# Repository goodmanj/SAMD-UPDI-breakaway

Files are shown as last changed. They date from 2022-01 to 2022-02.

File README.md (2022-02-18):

# SAMD-UPDI-breakaway
 A USB-to-UART-to-UPDI circuit board designed in KiCAD, based on Quentin Bolsee's [SAMD11C14 UART/UPDI programmer](https://fabacademy.org/2020/labs/ulb/students/quentin-bolsee/projects/samd11c_uart-updi/).  This version is designed so you can snap it in half to create a USB-to-UART adapter, and a UART-to-UPDI adapter, that can be used separately or joined together.  If you don't plan to use the "breakaway" feature, you don't need to solder in the 6-pin headers, and you might want to delete the internal slot to make it stronger.

* [Detailed assembly instructions](https://docs.google.com/document/d/1IBKZu-5q0hexmYGWNFWA64giY4mmglZQRK6Q2b19Nos/)
* [Quentin Bolsee's "SAMD11C_Serial" Arduino sketch](https://github.com/qbolsee/SAMD11C_serial): firmware for this board
* [Fab SAM Core for Arduino](https://github.com/qbolsee/ArduinoCore-fab-sam): Arduino core needed for Quentin's sketch

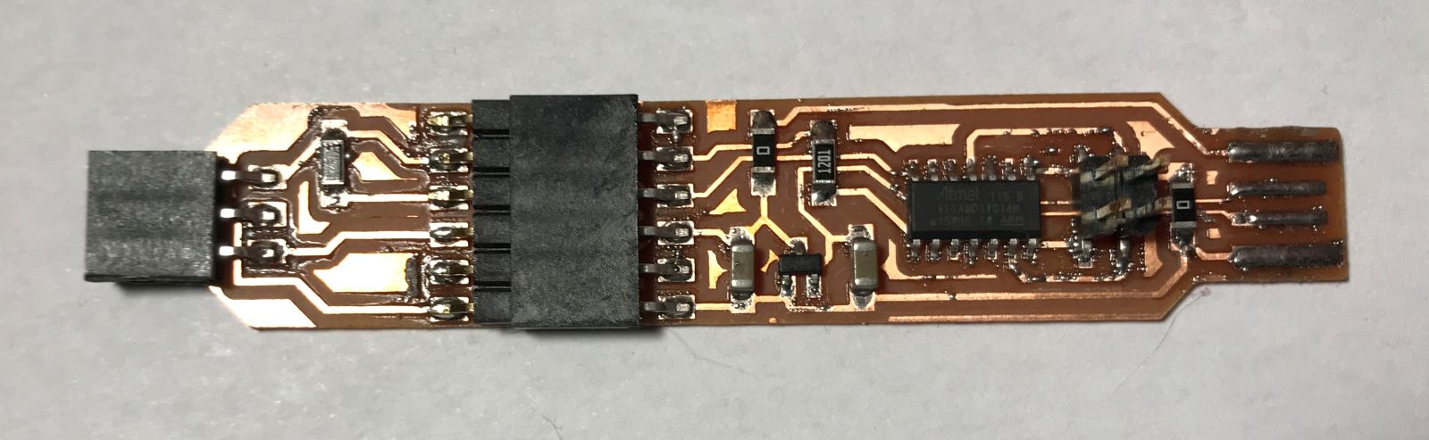
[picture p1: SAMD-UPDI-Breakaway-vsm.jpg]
Hero shot of board

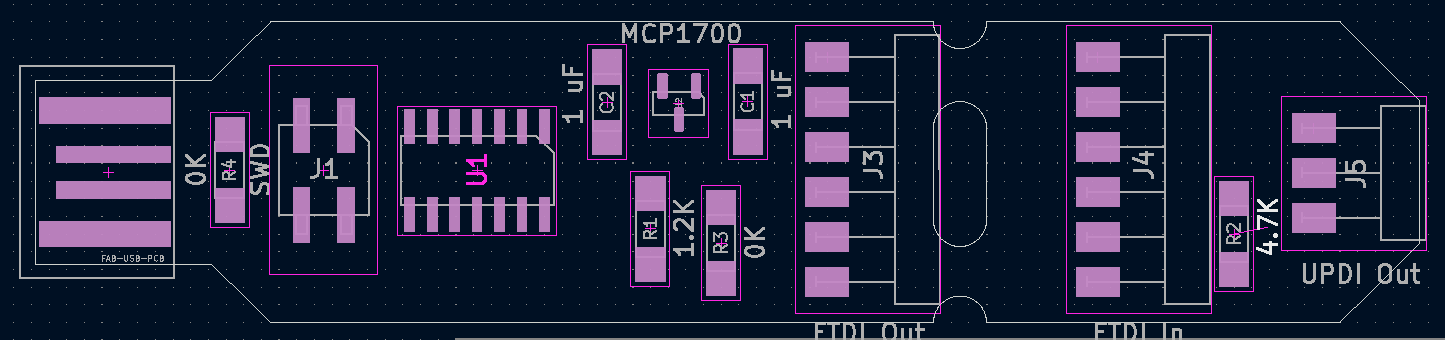
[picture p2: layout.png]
Component layout


## USB Port Backplate
You may find that the USB port is a little too skinny to fit nicely into some USB ports.  You can 3-d print a [Back Plate](BackPlate.stl) and glue or double-sided-tape it to the board to make it fit better.

 # Parts List
* [MCP1700T-3302E/TT LDO Voltage Regulator 5v->3.3v](https://www.mouser.com/ProductDetail/579-MCP1700T3302E-TT)
* [ATSAMD11C14A-SSNT SAMD microcontroller](https://www.mouser.com/ProductDetail/556-ATSAMD11C14ASSNT)
* [M20-8750242 2.54mm 2+2 DIL SMT header](https://www.mouser.com/ProductDetail/855-M20-8750242)
* [M20-8890645 2.54mm 6 way horzontal male SMT header](https://www.mouser.com/ProductDetail/855-M20-8890645)
* [M20-7910642R 2.54mm 6 way horzontal female SMT header](https://www.mouser.com/ProductDetail/855-M20-7910642R)  Qty: 2
* [1206 SMD resistor 4.7k](https://www.mouser.com/ProductDetail/652-CR1206-JW-472ELF)
* [1206 SMD resistor 1.2k](https://www.mouser.com/ProductDetail/652-CR1206FX-1201ELF)
* [1206 SMD zero-ohm SMD jumper](https://www.mouser.com/ProductDetail/652-CR1206-J-000ELF)
* [1206 SMD 1uF ceramic capacitors](https://www.mouser.com/ProductDetail/187-CL31B105KAHNFNE) Qty: 2

# Blinky Version
There is also a [version of this board with LED lights](Blinky-version/) to indicate serial data activity.  You will need two additional 1206 1.2k resistors, and two 1206 1.2k LEDs.

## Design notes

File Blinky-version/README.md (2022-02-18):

# Blinky Version
This version of the USB-to-UART-to-UPDI board includes LEDs to indicate serial port activity.  The red LED will turn on when this board has power: it will flicker *off* when data is being sent.  The green LED will turn on when the board you're talking to has power; it will flicker *off* when data is received.

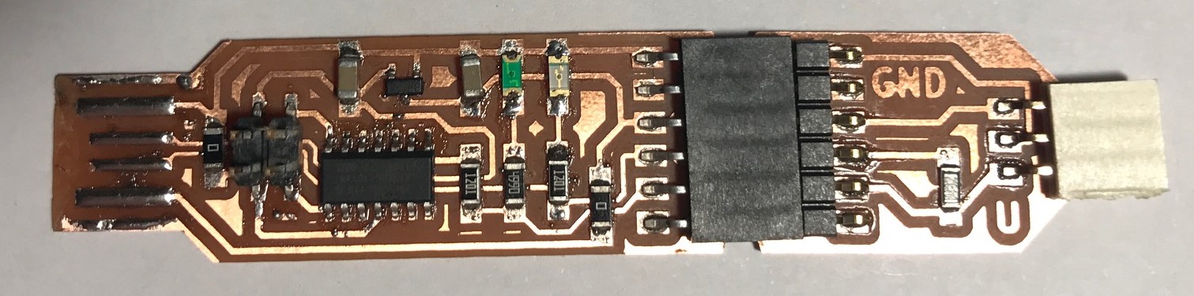
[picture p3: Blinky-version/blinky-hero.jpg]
Hero shot of board
 
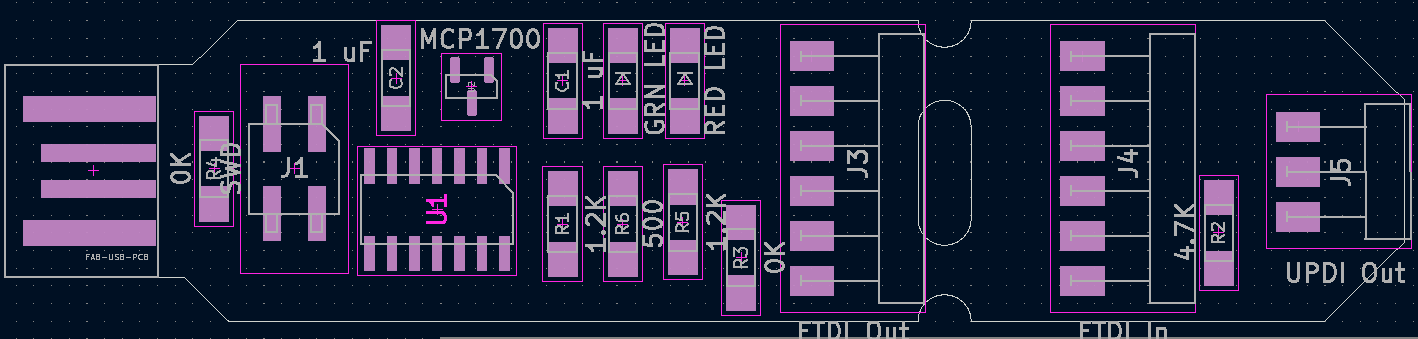
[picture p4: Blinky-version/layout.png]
Board Components
 
 # Parts List
* [MCP1700T-3302E/TT LDO Voltage Regulator 5v->3.3v](https://www.mouser.com/ProductDetail/579-MCP1700T3302E-TT)
* [ATSAMD11C14A-SSNT SAMD microcontroller](https://www.mouser.com/ProductDetail/556-ATSAMD11C14ASSNT)
* [M20-8750242 2.54mm 2+2 DIL SMT header](https://www.mouser.com/ProductDetail/855-M20-8750242)
* [M20-8890645 2.54mm 6 way horzontal male SMT header](https://www.mouser.com/ProductDetail/855-M20-8890645)
* [M20-7910642R 2.54mm 6 way horzontal female SMT header](https://www.mouser.com/ProductDetail/855-M20-7910642R)  Qty: 2
* [1206 SMD resistor 4.7k](https://www.mouser.com/ProductDetail/652-CR1206-JW-472ELF)
* [1206 SMD resistor 1.2k](https://www.mouser.com/ProductDetail/652-CR1206FX-1201ELF) Qty: 2
* [1206 SMD resistor 500](https://www.digikey.com/en/products/detail/yageo/RC1206FR-07499RL/728944) Qty: 1
* [1206 SMD zero-ohm SMD jumper](https://www.mouser.com/ProductDetail/652-CR1206-J-000ELF) Qty: 2
* [1206 SMD 1uF ceramic capacitors](https://www.mouser.com/ProductDetail/187-CL31B105KAHNFNE) Qty: 2
* [1206 SMD Red Clear LED](https://www.digikey.com/en/products/detail/liteon/LTST-C150CKT/269214)
* [1206 SMD Green Clear LED](https://www.digikey.com/en/products/detail/liteon/LTST-C150GKT/269216)

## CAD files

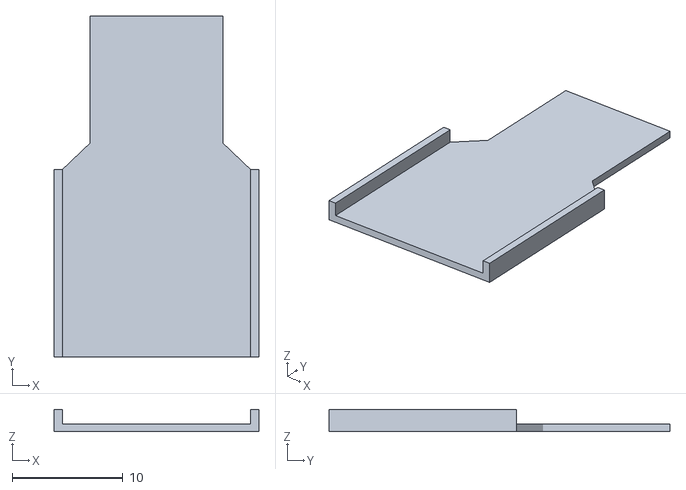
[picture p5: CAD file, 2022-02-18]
BackPlate.stl
18.5 x 30.8 x 2.00

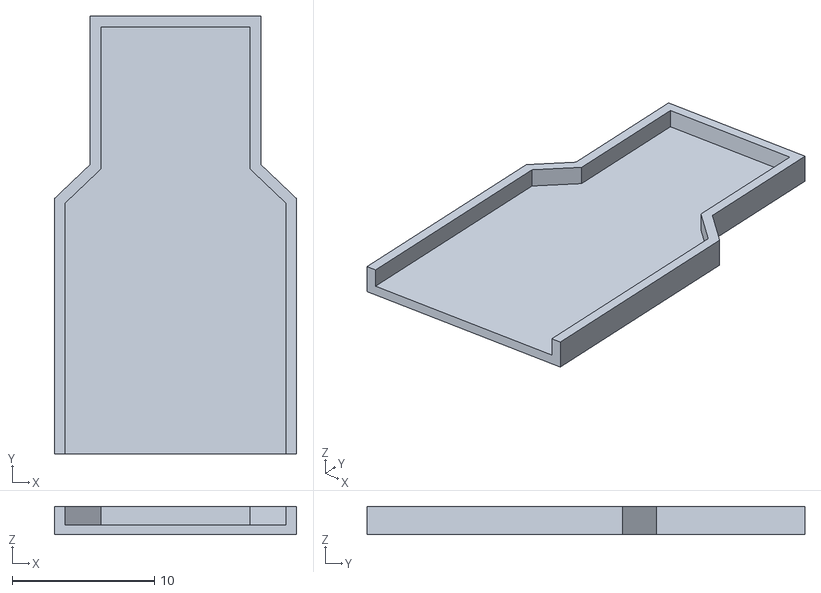
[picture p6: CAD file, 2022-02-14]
BackPlate-small.stl
17.0 x 30.8 x 2.00

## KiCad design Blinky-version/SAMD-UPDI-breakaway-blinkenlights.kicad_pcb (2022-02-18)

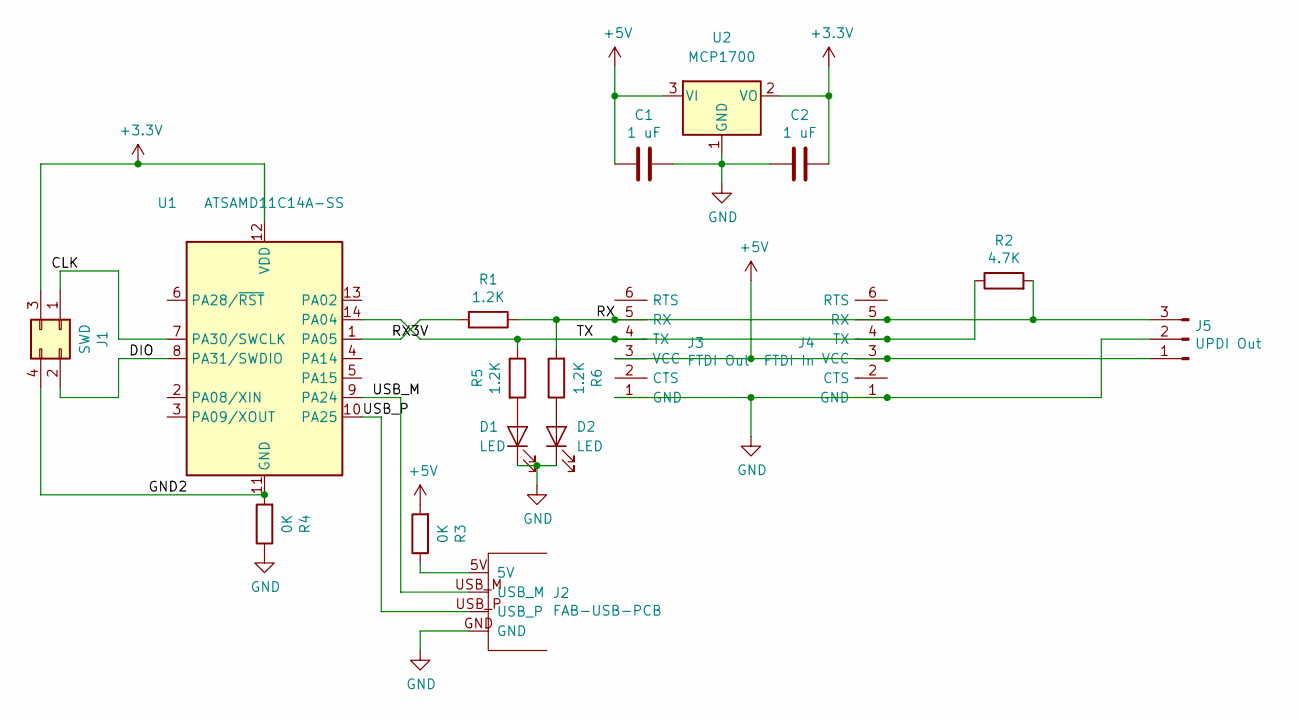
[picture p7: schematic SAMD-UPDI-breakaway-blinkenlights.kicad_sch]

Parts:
C1, C2: 1 uF; C_1206
D1, D2: LED; LED_1206
J1: SWD; PinHeader_2x02_P2.54mm_Vertical_SMD
J2: FAB-USB-PCB; FAB_USB-A-PCB
J3: FTDI Out; PinHeader_FTDI_01x06_P2.54mm_Horizontal_SMD
J4: FTDI In; PinHeader_FTDI_01x06_P2.54mm_Horizontal_SMD
J5: UPDI Out; PinHeader_1x03_P2.54mm_Horizontal_SMD
R1, R5, R6: 1.2K; R_1206
R2: 4.7K; R_1206
R3, R4: 0K; R_1206
U1: ATSAMD11C14A-SS; SOIC-14_3.9x8.7mm_P1.27mm
U2: MCP1700; SOT-23

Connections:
+3V3: C2.1, J1.3, U1.12 (VDD), U2.2 (VO)
+5V: C1.2, J3.3 (VCC), J4.3 (VCC), J5.1, R3.2, U2.3 (VI)
/DIO: J1.2, U1.8 (PA31/SWDIO)
/GND2: J1.4, R4.2, U1.11 (GND)
/RX: J3.5 (RX), J4.5 (RX), J5.3, R1.1, R2.2, R6.2
/RX3V: R1.2, U1.1 (PA05)
/TX: J3.4 (TX), J4.4 (TX), R2.1, R5.1, U1.14 (PA04)
/USB_M: J2.USB_M, U1.9 (PA24)
/USB_P: J2.USB_P, U1.10 (PA25)
GND: C1.1, C2.2, D1.1 (K), D2.1 (K), J2.GND, J3.1 (GND), J4.1 (GND), J5.2, R4.1, U2.1 (GND)
unnamed: D1.2 (A), R5.2
unnamed: D2.2 (A), R6.1
unnamed: J1.1, U1.7 (PA30/SWCLK)
unnamed: J2.5V, R3.1

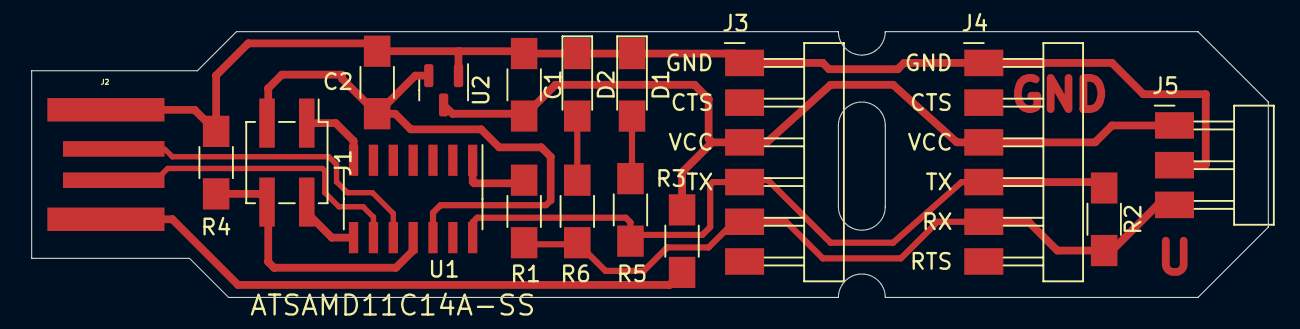
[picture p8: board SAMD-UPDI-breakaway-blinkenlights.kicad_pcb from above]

Board: 2 copper layers, 79.1 x 17.0 mm, 17 parts (0 on the bottom side), 14 nets.

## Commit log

2022-01-20 First draft, repo creation.
    Board hasn't been programmed or tested yet!
    [SAMD-UPDI-breakaway.kicad_pcb, SAMD-UPDI-breakaway.kicad_sch, SAMD-UPDI-breakaway.sch]
2022-02-14 Outline and Trace files added
    [SAMD-UPDI-breakaway.kicad_sch]
2022-02-14 Removed mill script file
2022-02-14 Added backplate STL
    [Back Plate.stl]
2022-02-16 Replace RST on JTAG header with Vref. Labels
    ATMEL Ice programmer doesn't use RST, but requires that the target microcontroller's VCC be provided for it to sense. Remove RST from JTAG header, provide VCC instead.
    [SAMD-UPDI-breakaway.kicad_pcb, SAMD-UPDI-breakaway.kicad_sch]
2022-02-16 Alternate version with LEDs to indicate serial activity
    [SAMD-UPDI-breakaway-blinkenlights.kicad_pcb, SAMD-UPDI-breakaway-blinkenlights.kicad_sch]
2022-02-18 Adjust USB size
    [SAMD-UPDI-breakaway.kicad_pcb]
2022-02-18 Updated Blinkenlights readme
    [SAMD-UPDI-breakaway-blinkenlights.kicad_pcb]
2022-02-18 Edit README to talk about backplate
    [BackPlate.stl]
2022-02-18 Make prettier component layout images
    [SAMD-UPDI-breakaway-blinkenlights.kicad_pcb, SAMD-UPDI-breakaway.kicad_pcb]
2022-02-18 Reverting USB size changes
    [SAMD-UPDI-breakaway.kicad_pcb]
2022-02-18 Adjust slot size
    [SAMD-UPDI-breakaway.kicad_pcb]
2022-02-18 Name change
    [SAMD-UPDI-breakaway-blinkenlights.kicad_pcb, SAMD-UPDI-breakaway-blinkenlights.kicad_sch]
2022-02-18 Tweak backplate design.
    BackPlate-small is for earlier USB designs.
    [BackPlate-small.stl, BackPlate.stl]
